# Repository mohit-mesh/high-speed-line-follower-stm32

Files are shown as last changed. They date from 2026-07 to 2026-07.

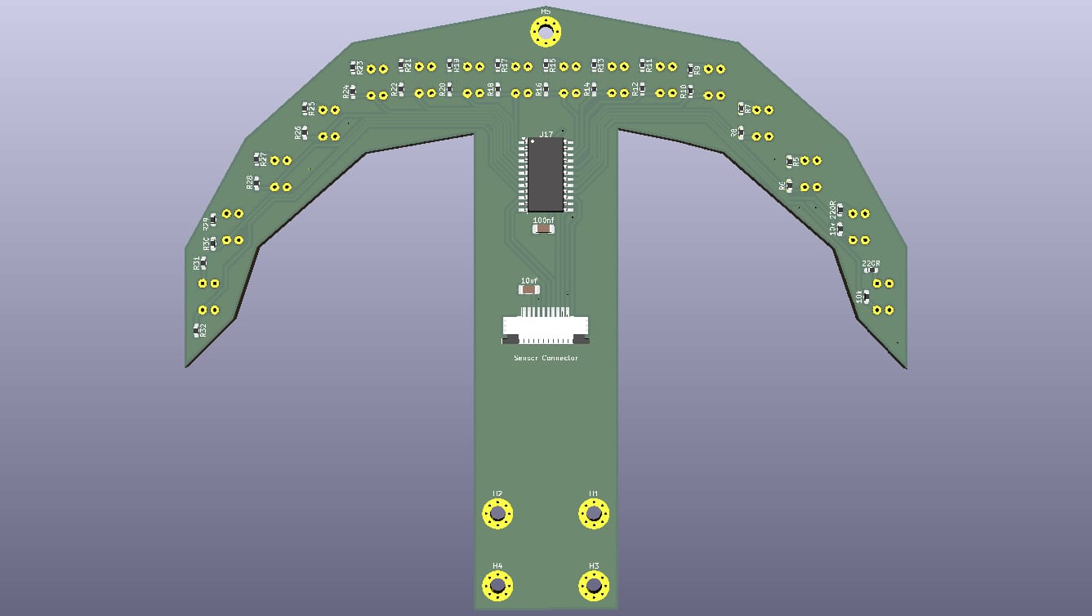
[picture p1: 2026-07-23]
hardware/16 array.jpeg

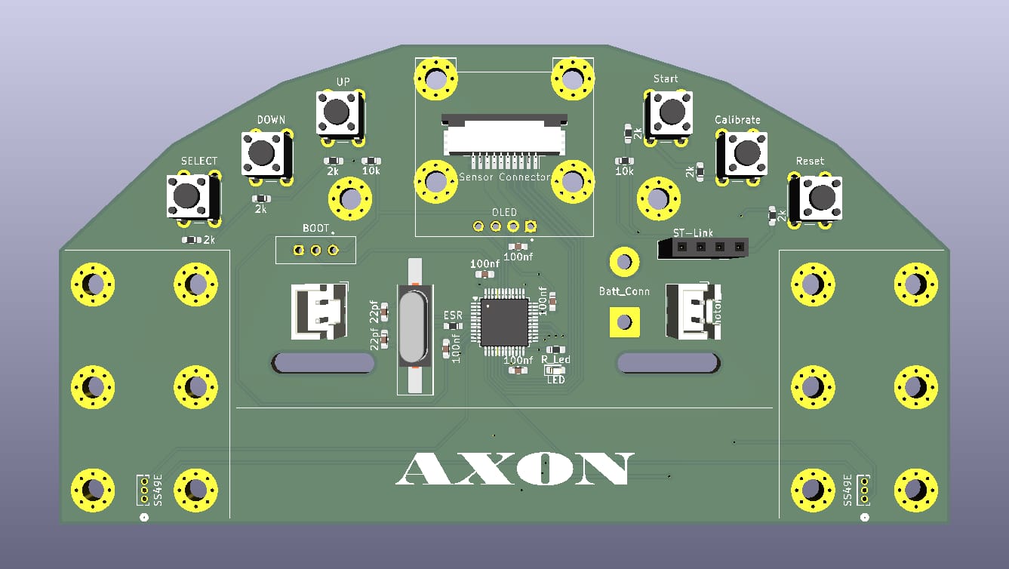
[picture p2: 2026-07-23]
hardware/main pcb.jpeg

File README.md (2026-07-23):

# High-Speed 16-IR Line Follower 🏎️⚡

16-ir robot

## 🏆 Project Overview

This repository contains the hardware design, custom PCBs, and C++ firmware for a high-speed, autonomous line-following robot. The system is engineered around the **STM32F103C8T6 (Blue Pill)** microcontroller and utilizes a dense **16-channel IR sensor array** to achieve millimeter-level error detection and ultra-smooth trajectory correction at high velocities.

## ⚙️ System Architecture & Tech Stack

By moving away from basic 8-bit microcontrollers and off-the-shelf modules, this project leverages custom hardware and a 32-bit ARM Cortex-M3 processor to handle complex floating-point math and high-frequency sensor polling without bottlenecking the main control loop.

* **Microcontroller:** STM32F103C8T6 (Blue Pill)
* **Firmware Language:** C++ (STM32 HAL)
* **Control Algorithm:** Tuned **PID (Proportional-Integral-Derivative)** Controller
* **Hardware Design:** Custom-designed Main Control Board & 16-IR Sensor Array PCBs
* **User Interface:** I2C OLED Display for real-time parameter tuning

### 🖥️ On-the-Fly Tuning (OLED Integration)

To eliminate the tedious process of hardcoding variables and constantly re-flashing the microcontroller during track testing, this robot features a custom onboard UI utilizing an **OLED display**. This allows for immediate, on-the-go diagnostics and optimization:

* **Live PID Tuning:** Adjust proportional ($K_p$), integral ($K_i$), and derivative ($K_d$) values directly on the starting grid.
* **Speed Profiling:** Modify base speeds and maximum cornering velocities instantly.
* **Telemetry & Lap Times:** View previous lap times immediately after completing a run to track optimization progress and benchmark different PID configurations.

### 🔌 Custom PCB Design

To ensure signal integrity at high speeds and eliminate messy wiring, I designed custom PCBs for this project:

1. **Main Control Board:** Integrates the STM32 microcontroller, motor drivers, OLED display, and power distribution into a single, compact footprint to lower the robot's center of gravity.

2. **16-IR Sensor Array Board:** Standard 5-IR arrays limit a robot to jerky, bang-bang control. By designing a custom 16-IR array, the microcontroller receives a highly granular, continuous gradient of the line's position. This allows the derivative ($K_d$) and proportional ($K_p$) terms to calculate precise motor speed adjustments, preventing overshoot even at top speeds.

main pcb  16 array

## 📂 Repository Structure

```text
├── firmware/            # STM32 C++ source code, headers, and .ioc configuration
├── hardware/            # PCB design files (Schematics, Layout, Gerbers)
├── cad/                 # 3D models (.step) for the chassis and sensor brackets
├── docs/                # Media and additional documentation
└── README.md

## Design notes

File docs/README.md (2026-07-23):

## 📸 Media & Documentation

This directory contains the visual documentation for the high-speed 16-IR line follower project. Seeing the robot in action is the best way to understand the effectiveness of the PID tuning and the high-resolution sensor array.

### 🎥 Video Demonstrations

| Demonstration | Description | Link |
|---|---|---|
| **Final High-Speed Run** | The robot navigating a complex track with sharp turns and crossovers at top speed. | [🔗 Watch Video](https://youtu.be/PEw2EPQcNDo) |
| **PID Tuning Demo** | A short clip showing the OLED interface in use and how parameter changes affect cornering behavior. | [🔗 Watch Video](INSERT_LINK_HERE) |

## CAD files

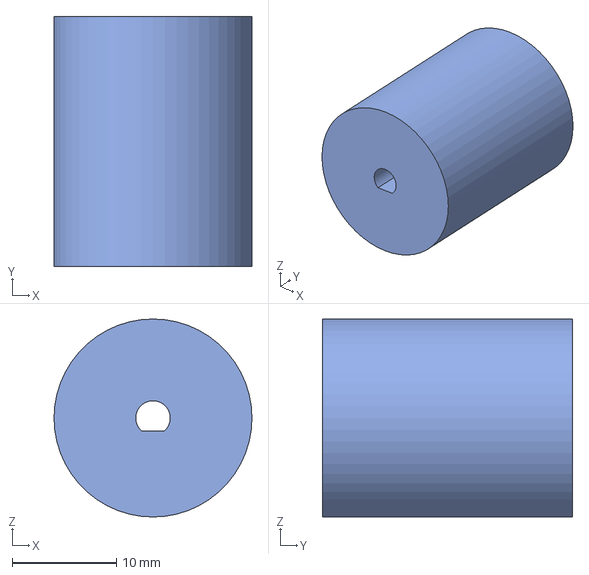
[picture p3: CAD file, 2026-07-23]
cad/N20 Wheel (3).step
19.0 x 24.0 x 19.0 mm

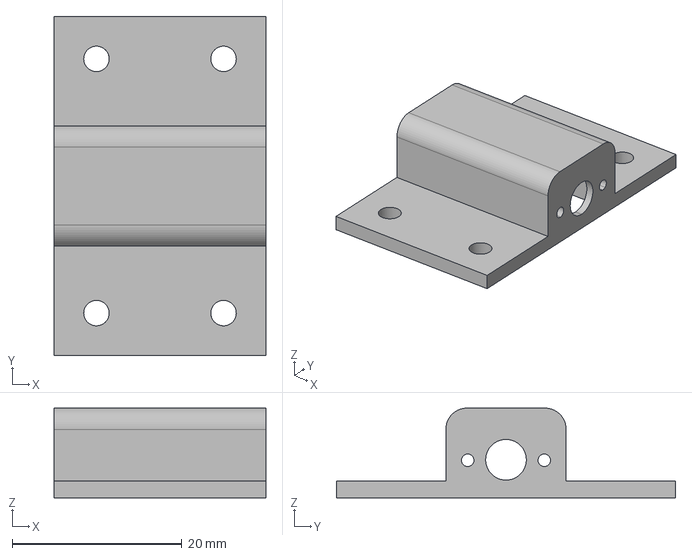
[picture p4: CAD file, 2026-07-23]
cad/n20 mount.step
25.0 x 40.0 x 10.6 mm

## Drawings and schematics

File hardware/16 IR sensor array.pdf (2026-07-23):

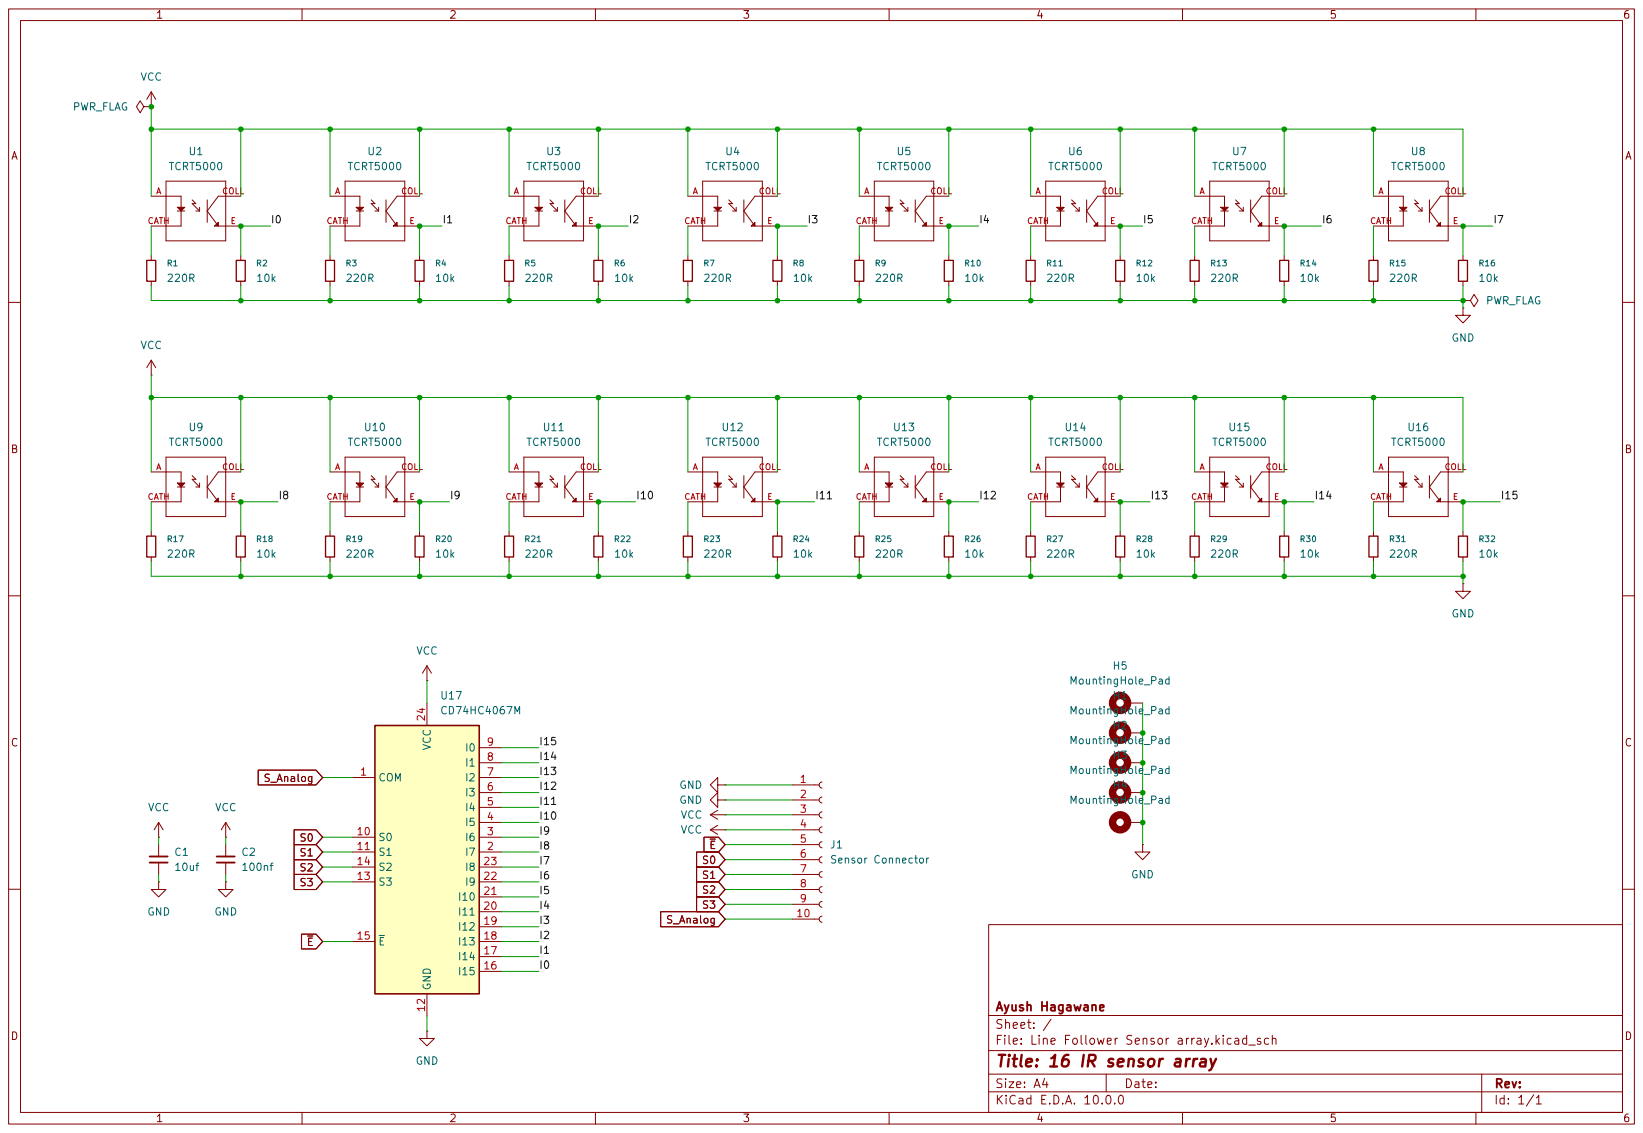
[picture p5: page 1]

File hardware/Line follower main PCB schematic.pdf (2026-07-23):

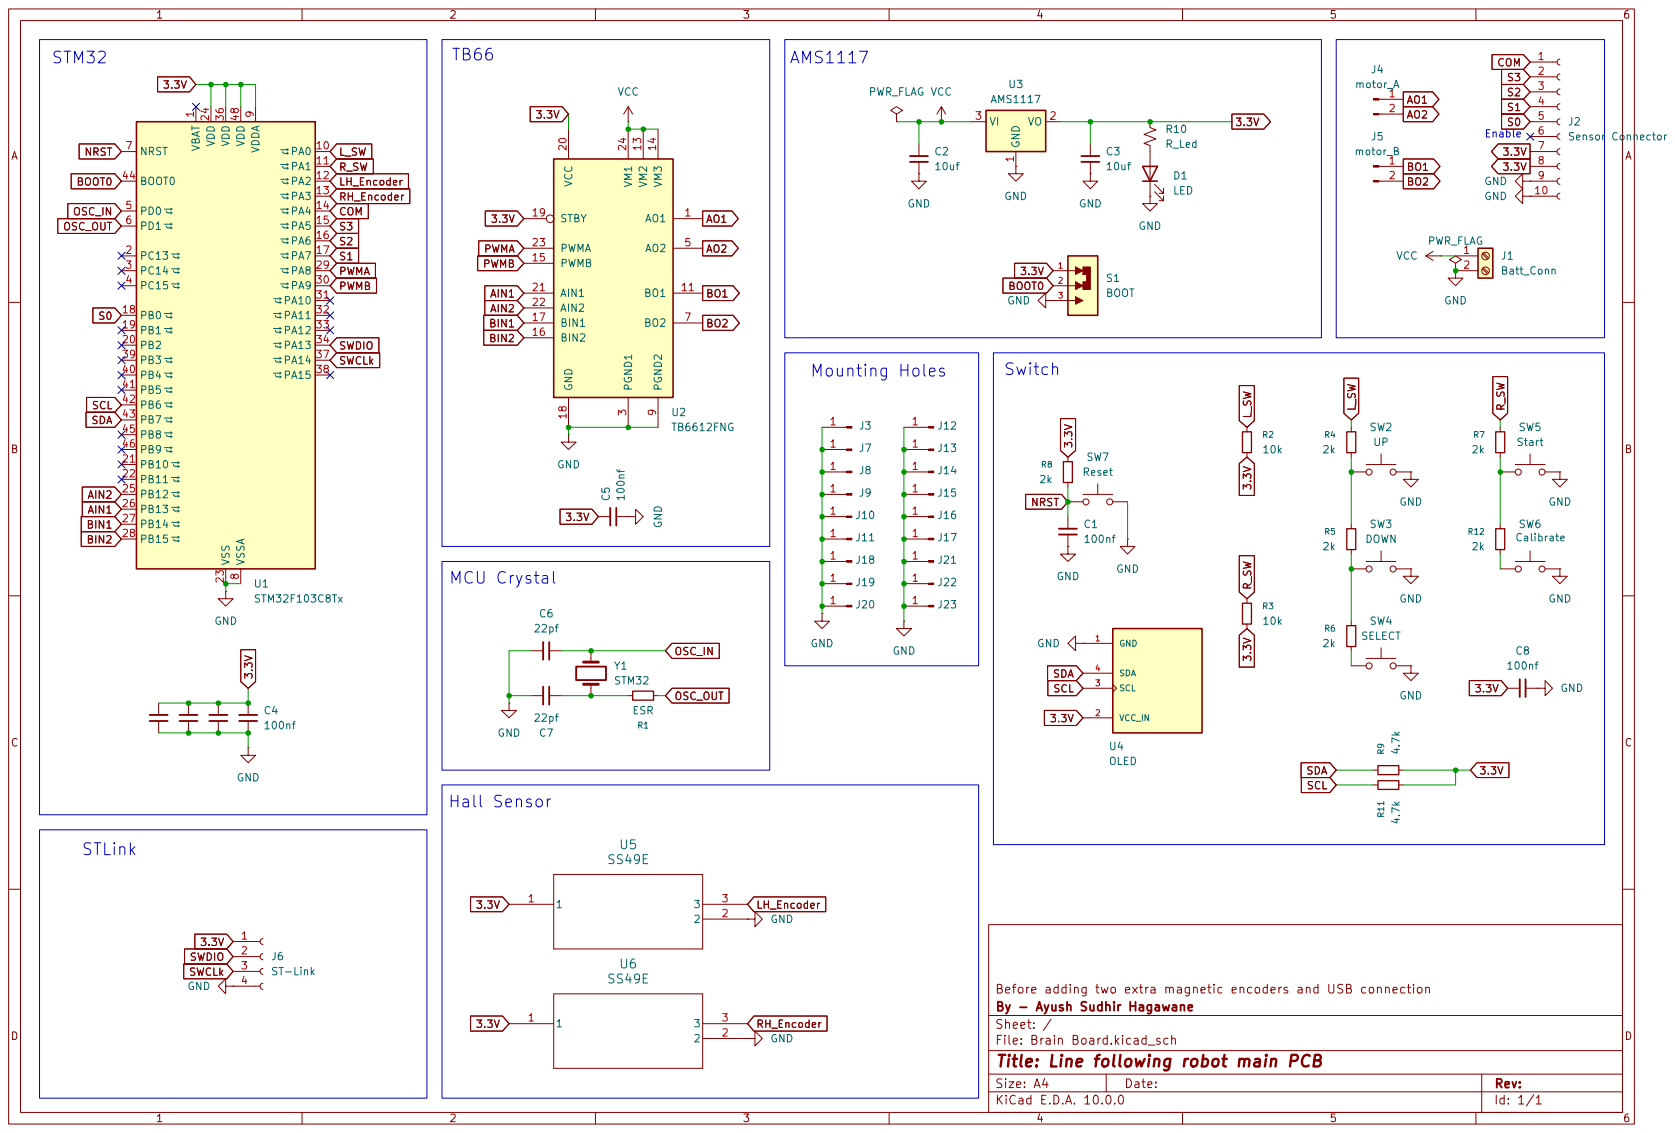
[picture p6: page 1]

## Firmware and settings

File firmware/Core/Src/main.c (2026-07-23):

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
/* Includes ------------------------------------------------------------------*/
#include "main.h"

/* USER CODE BEGIN Includes */
#include "ssd1306.h"
#include "ssd1306_tests.h" // Optional
#include "ssd1306_fonts.h"
#include <stdio.h>
#include "lfr.h"

/* USER CODE END Includes */

ADC_HandleTypeDef hadc1;

I2C_HandleTypeDef hi2c1;

TIM_HandleTypeDef htim1;
TIM_HandleTypeDef htim2;

void SystemClock_Config(void);
static void MX_GPIO_Init(void);
static void MX_ADC1_Init(void);
static void MX_I2C1_Init(void);
static void MX_TIM1_Init(void);
static void MX_TIM2_Init(void);
/* USER CODE BEGIN 0 */
uint32_t read_adc_channel(uint32_t channel) {
    ADC_ChannelConfTypeDef sConfig = {0};
    sConfig.Channel = channel;
    sConfig.Rank = ADC_REGULAR_RANK_1;
    sConfig.SamplingTime = ADC_SAMPLETIME_71CYCLES_5;
    if (HAL_ADC_ConfigChannel(&hadc1, &sConfig) != HAL_OK) {
        Error_Handler();
    }
    HAL_ADC_Start(&hadc1);
    HAL_ADC_PollForConversion(&hadc1, 100);
    uint32_t val = HAL_ADC_GetValue(&hadc1);
    HAL_ADC_Stop(&hadc1);
    return val;
}

/* USER CODE END 0 */

/**
  * @brief  The application entry point.
  * @retval int
  */
int main(void)
{

  /* MCU Configuration--------------------------------------------------------*/

  /* Reset of all peripherals, Initializes the Flash interface and the Systick. */
  HAL_Init();

  /* Configure the system clock */
  SystemClock_Config();

  /* Initialize all configured peripherals */
  MX_GPIO_Init();
  MX_ADC1_Init();
  MX_I2C1_Init();
  MX_TIM1_Init();
  MX_TIM2_Init();
  /* USER CODE BEGIN 2 */
  LFR_Init();
  HAL_TIM_Base_Start_IT(&htim2);

  ssd1306_Init();
  HAL_Delay(100);
  ssd1306_Fill(Black);
  ssd1306_SetCursor(14, 23);
  ssd1306_WriteString("Team Axon", Font_11x18, White);
  ssd1306_UpdateScreen();
  HAL_Delay(2000);

  /* USER CODE END 2 */

  /* Infinite loop */
  /* USER CODE BEGIN WHILE */
  typedef enum {
      STATE_MAIN_MENU,
      STATE_PID_MENU,
      STATE_TUNE_VAL,
      STATE_STOPWATCH,
      STATE_RUN_TIMES,
      STATE_TUNE_SPEED
  } MenuState_t;

  MenuState_t current_state = STATE_MAIN_MENU;
  uint8_t main_menu_index = 0;
  uint8_t pid_menu_index = 0;

  // ==========================================
  // HARDCODED DEFAULT SETTINGS
  // Change these values to set the startup PID 
  // and speed directly from the code!
  // ==========================================
  float pid_p = 0.2f;      // Proportional (Start 0.1 - 0.3)
  float pid_i = 0.0f;      // Integral (Keep at 0 until P and D are perfect)
  float pid_d = 3.0f;      // Derivative (Start 1.0 - 5.0)
  int robot_speed = 1500;  // Base speed (0 to 3599) - Lowered to 1500 for testing
  int motor_offset = 0;    // Reset offset to 0. A massive offset saturates the motors!
  // ==========================================

  uint8_t prev_up = 0;
  uint8_t prev_down = 0;
  uint8_t prev_select = 0;
  uint8_t prev_start = 0;

  uint32_t stopwatch_start_time = 0;
  uint32_t run_times[15] = {0};
  uint8_t num_run_times = 0;
  uint8_t run_times_scroll = 0;

  const char* menu_options[3] = {
      "PID Tuning",
      "Speed Tuning",
      "Run Times"
  };

  const char* pid_options[4] = {
      "Tune P",
      "Tune I",
      "Tune D",
      "Back"
  };

  while (1)
  {
      uint32_t l_sw_val = LFR_GetSwitchL();
      uint32_t r_sw_val = LFR_GetSwitchR();

      uint8_t btn_up = (l_sw_val > 400 && l_sw_val < 900) ? 1 : 0;
      uint8_t btn_down = (l_sw_val >= 900 && l_sw_val < 1350) ? 1 : 0;
      uint8_t btn_select = (l_sw_val >= 1350 && l_sw_val < 1800) ? 1 : 0;

      uint8_t btn_start = (r_sw_val > 400 && r_sw_val < 900) ? 1 : 0;
      uint8_t btn_calibrate = (r_sw_val >= 900 && r_sw_val < 1350) ? 1 : 0;

      // Start Button Logic (Stopwatch)
      if (btn_start && !prev_start) {
          if (current_state == STATE_MAIN_MENU) {
              current_state = STATE_STOPWATCH;
              stopwatch_start_time = HAL_GetTick();
              
              LFR_SetPID(pid_p, pid_i, pid_d);
              LFR_SetBaseSpeed(robot_speed);
              LFR_SetMotorOffset(motor_offset);
              LFR_Start();
          } else if (current_state == STATE_STOPWATCH) {
              LFR_Stop();
              
              uint32_t elapsed = HAL_GetTick() - stopwatch_start_time;

              // Shift history down and insert at top
              for (int i = 14; i > 0; i--) {
                  run_times[i] = run_times[i-1];
              }
              run_times[0] = elapsed;
              if (num_run_times < 15) num_run_times++;

              // Return to main menu
              current_state = STATE_MAIN_MENU;
          }
      }
      prev_start = btn_start;

      // Calibrate Button Logic
      if (btn_calibrate && current_state == STATE_MAIN_MENU) {
          LFR_Calibrate();
          
          // Make the robot rotate automatically during calibration
          LFR_SetMotors(1500, -1500);

          const char* dots_str[4] = {"", ".", "..", "..."};
          uint32_t cal_start = HAL_GetTick();
          uint32_t elapsed = 0;
          
          while ((elapsed = HAL_GetTick() - cal_start) <= 10000) {
              ssd1306_Fill(Black);

              char cal_str[20];
              sprintf(cal_str, "Calibrating%s", dots_str[(elapsed / 500) % 4]);
              ssd1306_SetCursor(18, 15);
              ssd1306_WriteString(cal_str, Font_7x10, White);

              // Draw progress bar outline
              ssd1306_DrawRectangle(14, 32, 114, 42, White);

              // Fill progress bar (max width 96)
              int fill_width = (elapsed * 96) / 10000;
              if (fill_width > 0) {
                  ssd1306_FillRectangle(16, 34, 16 + fill_width, 40, White);
              }

              // Percentage text
              char pct_str[10];
              sprintf(pct_str, "%lu%%", (elapsed * 100) / 10000);
              ssd1306_SetCursor(55, 48);
              ssd1306_WriteString(pct_str, Font_6x8, White);

              ssd1306_UpdateScreen();
          }

          // Calibration complete message
          LFR_EndCalibrate();
          
          // Stop rotating
          LFR_SetMotors(0, 0);
          
          ssd1306_Fill(Black);
          ssd1306_SetCursor(28, 25);
          ssd1306_WriteString("Complete!", Font_7x10, White);
          ssd1306_UpdateScreen();
          HAL_Delay(1500);

          // Force clear previous button states to prevent phantom clicks
          prev_up = prev_down = prev_select = 0;
          continue; // Restart the loop
      }

      // State machine for menu navigation
      if (btn_up && !prev_up) {
          if (current_state == STATE_MAIN_MENU) {
              main_menu_index = (main_menu_index == 0) ? 2 : main_menu_index - 1;
          } else if (current_state == STATE_PID_MENU) {
              pid_menu_index = (pid_menu_index == 0) ? 3 : pid_menu_index - 1;
          } else if (current_state == STATE_TUNE_VAL) {
              if (pid_menu_index == 0) pid_p += 0.1f;
              else if (pid_menu_index == 1) pid_i += 0.0001f;
              else if (pid_menu_index == 2) pid_d += 0.1f;
          } else if (current_state == STATE_RUN_TIMES) {
              if (run_times_scroll > 0) run_times_scroll--;
          } else if (current_state == STATE_TUNE_SPEED) {
              if (robot_speed <= 4080) robot_speed += 10;
              else robot_speed = 4090; // clamp
          }
      }
      if (btn_down && !prev_down) {
          if (current_state == STATE_MAIN_MENU) {
              main_menu_index = (main_menu_index == 2) ? 0 : main_menu_index + 1;
          } else if (current_state == STATE_PID_MENU) {
              pid_menu_index = (pid_menu_index == 3) ? 0 : pid_menu_index + 1;
          } else if (current_state == STATE_TUNE_VAL) {
              if (pid_menu_index == 0) pid_p -= 0.1f;
              else if (pid_menu_index == 1) pid_i -= 0.0001f;
              else if (pid_menu_index == 2) pid_d -= 0.1f;
          } else if (current_state == STATE_RUN_TIMES) {
              if (num_run_times > 4 && run_times_scroll < num_run_times - 4) {
                  run_times_scroll++;
              }
          } else if (current_state == STATE_TUNE_SPEED) {
              if (robot_speed >= 10) robot_speed -= 10;
              else robot_speed = 0; // clamp
          }
      }
      if (btn_select && !prev_select) {
          if (current_state == STATE_MAIN_MENU) {
              if (main_menu_index == 0) { // PID Tuning
                  current_state = STATE_PID_MENU;
                  pid_menu_index = 0;
              } else if (main_menu_index == 1) { // Speed Tuning
                  current_state = STATE_TUNE_SPEED;
              } else if (main_menu_index == 2) { // Run Times
                  current_state = STATE_RUN_TIMES;
                  run_times_scroll = 0;
              }
          } else if (current_state == STATE_PID_MENU) {
              if (pid_menu_index == 3) { // Back
                  current_state = STATE_MAIN_MENU;
              } else {
                  current_state = STATE_TUNE_VAL;
              }
          } else if (current_state == STATE_TUNE_VAL) {
              // Press select again to confirm and return to PID menu
              current_state = STATE_PID_MENU;
          } else if (current_state == STATE_RUN_TIMES) {
              // Press select to return to main menu
              current_state = STATE_MAIN_MENU;
          } else if (current_state == STATE_TUNE_SPEED) {
              current_state = STATE_MAIN_MENU;
          }
      }

      prev_up = btn_up;
      prev_down = btn_down;
      prev_select = btn_select;

      // Render Menu
      ssd1306_Fill(Black);

      if (current_state == STATE_MAIN_MENU || current_state == STATE_PID_MENU) {
          uint8_t num_options = (current_state == STATE_MAIN_MENU) ? 3 : 4;
          uint8_t active_idx = (current_state == STATE_MAIN_MENU) ? main_menu_index : pid_menu_index;
          const char** options_arr = (current_state == STATE_MAIN_MENU) ? menu_options : pid_options;

          // Draw shallow arc/curve on the left
          ssd1306_Line(2, 5, 6, 18, White);
          ssd1306_Line(6, 18, 10, 32, White);
          ssd1306_Line(10, 32, 6, 46, White);
          ssd1306_Line(6, 46, 2, 59, White);

          // Top Item (Previous)
          int prev_idx = (active_idx == 0) ? num_options - 1 : active_idx - 1;
          ssd1306_DrawCircle(6, 15, 2, White);
          ssd1306_SetCursor(16, 11);
          ssd1306_WriteString((char*)options_arr[prev_idx], Font_6x8, White);

          // Center Item (Selected)
          ssd1306_DrawCircle(10, 32, 3, White);
          ssd1306_FillCircle(10, 32, 1, White);
          ssd1306_Line(13, 32, 18, 32, White);

          // Highlight bar
          ssd1306_FillRectangle(18, 23, 127, 41, White);
          ssd1306_SetCursor(22, 27);
          ssd1306_WriteString((char*)options_arr[active_idx], Font_7x10, Black);

          // Bottom Item (Next)
          int next_idx = (active_idx == num_options - 1) ? 0 : active_idx + 1;
          ssd1306_DrawCircle(6, 49, 2, White);
          ssd1306_SetCursor(16, 45);
          ssd1306_WriteString((char*)options_arr[next_idx], Font_6x8, White);
      }
      else if (current_state == STATE_TUNE_VAL) {
          // Tune Value Screen
          ssd1306_SetCursor(36, 5);
          if (pid_menu_index == 0) ssd1306_WriteString("Tuning P", Font_7x10, White);
          else if (pid_menu_index == 1) ssd1306_WriteString("Tuning I", Font_7x10, White);
          else if (pid_menu_index == 2) ssd1306_WriteString("Tuning D", Font_7x10, White);

          char val_str[16];
          float val = (pid_menu_index == 0) ? pid_p : (pid_menu_index == 1) ? pid_i : pid_d;

          // Manual float to string to avoid printf %f missing library issues
          int sign = (val < 0) ? -1 : 1;
          val *= sign;
          int int_part = (int)val;

          if (pid_menu_index == 1) { // 4 decimals for I
              int frac_part = (int)((val - int_part) * 10000.0f + 0.5f);
              if (frac_part >= 10000) { int_part++; frac_part -= 10000; }
              sprintf(val_str, "%s%d.%04d", (sign < 0) ? "-" : "", int_part, frac_part);
          } else { // 1 decimal for P and D
              int frac_part = (int)((val - int_part) * 10.0f + 0.5f);
              if (frac_part >= 10) { int_part++; frac_part -= 10; }
              sprintf(val_str, "%s%d.%01d", (sign < 0) ? "-" : "", int_part, frac_part);
          }

          // Draw neat bounding box
          ssd1306_DrawRectangle(10, 20, 118, 48, White);
          ssd1306_SetCursor(20, 27);
          ssd1306_WriteString(val_str, Font_11x18, White);

          // Draw UP / DOWN hints
          ssd1306_SetCursor(13, 54);
          ssd1306_WriteString("[UP/DN to adjust]", Font_6x8, White);
      }
      else if (current_state == STATE_TUNE_SPEED) {
          // Tune Speed Screen
          ssd1306_SetCursor(22, 5);
          ssd1306_WriteString("Tuning Speed", Font_7x10, White);

          char val_str[16];
          int len = sprintf(val_str, "%d", robot_speed);

          // Draw neat bounding box
          ssd1306_DrawRectangle(10, 20, 118, 48, White);

          // Dynamically center the number based on its length
          int x_pos = 10 + (108 - (len * 11)) / 2;
          ssd1306_SetCursor(x_pos, 27);
          ssd1306_WriteString(val_str, Font_11x18, White);

          // Draw UP / DOWN hints
          ssd1306_SetCursor(13, 54);
          ssd1306_WriteString("[UP/DN to adjust]", Font_6x8, White);
      }
      else if (current_state == STATE_STOPWATCH) {
          // Stopwatch Screen
          ssd1306_SetCursor(38, 5);
          ssd1306_WriteString("STOPWATCH", Font_7x10, White);

          uint32_t elapsed = HAL_GetTick() - stopwatch_start_time;
          uint32_t ms = elapsed % 1000;
          uint32_t sec = (elapsed / 1000) % 60;
          uint32_t min = (elapsed / 60000);

          char time_str[16];
          sprintf(time_str, "%02lu:%02lu.%03lu", min, sec, ms);

          // Draw neat bounding box
          ssd1306_DrawRectangle(10, 20, 118, 48, White);
          ssd1306_SetCursor(18, 27);
          ssd1306_WriteString(time_str, Font_11x18, White);

          ssd1306_SetCursor(16, 54);
          ssd1306_WriteString("[START to return]", Font_6x8, White);
      }
      else if (current_state == STATE_RUN_TIMES) {
          ssd1306_SetCursor(32, 0);
          ssd1306_WriteString("RUN TIMES", Font_7x10, White);
          ssd1306_Line(0, 12, 127, 12, White);

          if (num_run_times == 0) {
              ssd1306_SetCursor(10, 30);
              ssd1306_WriteString("No runs yet!", Font_7x10, White);
          } else {
              for (int i = 0; i < 4; i++) {
                  int idx = run_times_scroll + i;
                  if (idx >= num_run_times) break;

                  uint32_t elapsed = run_times[idx];
                  uint32_t ms = elapsed % 1000;
                  uint32_t sec = (elapsed / 1000) % 60;
                  uint32_t min = (elapsed / 60000);

                  char time_str[24];
                  sprintf(time_str, "%2d.%02lu:%02lu.%03lu", idx + 1, min, sec, ms);

                  ssd1306_SetCursor(5, 16 + i * 11);
                  ssd1306_WriteString(time_str, Font_7x10, White);
              }

              // Draw scroll indicator if list overflows
              if (num_run_times > 4) {
                  int scroll_y = 15 + (run_times_scroll * 30) / (num_run_times - 4);
                  ssd1306_DrawRectangle(124, 15, 127, 55, White);
                  ssd1306_FillRectangle(124, scroll_y, 127, scroll_y + 10, White);
              }
          }

          ssd1306_SetCursor(13, 56);
          ssd1306_WriteString("[SELECT to return]", Font_6x8, White);
      }

      ssd1306_UpdateScreen();
      HAL_Delay(50); // Small delay for button debouncing
    /* USER CODE END WHILE */

    /* USER CODE BEGIN 3 */
  }
  /* USER CODE END 3 */
}

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
/* USER CODE BEGIN 4 */
void HAL_TIM_PeriodElapsedCallback(TIM_HandleTypeDef *htim) {
    if (htim->Instance == TIM2) {
        LFR_ControlLoop();
    }
}
/* USER CODE END 4 */
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


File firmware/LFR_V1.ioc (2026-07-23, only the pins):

Mcu.UserName=STM32F103C8Tx
PA0-WKUP.Signal=ADCx_IN0
PA1.Signal=ADCx_IN1
PA13.Signal=SYS_JTMS-SWDIO
PA14.Signal=SYS_JTCK-SWCLK
PA2.Signal=ADCx_IN2
PA3.Signal=ADCx_IN3
PA4.Signal=ADCx_IN4
PA5.Signal=GPIO_Output
PA6.Signal=GPIO_Output
PA7.Signal=GPIO_Output
PA8.Signal=S_TIM1_CH1
PA9.Signal=S_TIM1_CH2
PB0.Signal=GPIO_Output
PB12.Signal=GPIO_Output
PB13.Signal=GPIO_Output
PB14.Signal=GPIO_Output
PB15.Signal=GPIO_Output
PB6.Signal=I2C1_SCL
PB7.Signal=I2C1_SDA
PD0-OSC_IN.Signal=RCC_OSC_IN
PD1-OSC_OUT.Signal=RCC_OSC_OUT

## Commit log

2026-07-23 Revise README with project details and structure
    Updated project title, added detailed project overview, system architecture, and custom PCB design sections to README.
2026-07-23 Update README with image and repository structure
    Added an image reference for the 16-IR Sensor Array Board and updated the repository structure section.
2026-07-23 Add images for 16-IR array and main PCB
    Added an image of the main PCB alongside the 16-IR array image in the README.

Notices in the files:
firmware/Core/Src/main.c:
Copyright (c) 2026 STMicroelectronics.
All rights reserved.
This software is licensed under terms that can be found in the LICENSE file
